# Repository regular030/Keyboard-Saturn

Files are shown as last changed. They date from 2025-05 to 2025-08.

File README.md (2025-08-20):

# **Keyboard Saturn, A Simple Keyboard With An OLED Display**

98a7035d-8480-496f-965c-6c204143d6b0



# **YouTube Video:**
https://youtu.be/Gn7tNZ5N1NY

# **Why Did I Make This**

After Hackpad, I started getting recommended lots of Scotto Keebs videos on YouTube, which made me much more interested in making my own keyboard. Now that I have more free time, I decided to make my 5-month-in-thought project a reality.

# **Design Choices**
- SN74HC165N
  - Instead of using any other GPIO expanders, I wanted to use the SN because it is an 8-bit parallel-load shift register, instead of using the I2C protocol to communicate with the MCU, which is around 8 times faster
- Raspberry Pi Pico
  - Cheap and Reliable
- OLED 32-128
  -  Just wanted to add a display where I can show whether or not NUM/CAPS/SCRL lock is on, + show Spotify music, + other stuff
- 100% Layout
  - I use the Numpad for anything numbers-related
- Minimalist chassis design
  - I just wanted to make something  that was simple and looked clean, kind of like Cybertruck, but better 
 
# **Files**
<br>
chassis
<br>

- .Step files for the chassis + PCB
  - KeyboardL.step
      - Bottom left side of keyboard
  - KeyboardM.step
      - Bottom middle side of keyboard
  - KeyboardR.step
      - Bottom right side of keyboard
  - KeyboardTop.step
      - Top side of the keyboard
      - Use M2 screws to screw it into the bottom parts (screw holes in top and bottom in the middle, left and right sections) 
  - insert-keyboard v1.step
      - The inserts for the keyboard to connect KeyboardM, KeyboardL and KeyboardR, please use super glue to make sure they are in, then super glue the chassis together
<br>
kicad
<br>

- All the KiCad 8.0.5 files for the project 

# **BOM:**


https://docs.google.com/spreadsheets/d/1oLEcZ3zztSK3hqa6-qvamrNF2S6u_cLABAHxks2xx3M/edit?usp=sharing

# THIS PROJECT IS NOW DEPRECATED. IT WILL NOT BE GETTING ANY MORE SUPPORT. V2 is a possibility

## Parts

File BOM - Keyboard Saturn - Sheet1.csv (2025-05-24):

Part Name | QTY | Price Per | Link | Notes
Raspberry Pi Pico (U1) | 1 | US $2.08
SN74HC165N (U2) | 1 | US $1.73 |  | buying one more Incase I screw up
OLED 128x32 (J1) | 1 | US $0.99
Resistor 2kohms (R1-R4) pack of 100 | 1 | US $1.67 |  | lowest # I can get
Diode IN4148 (D1-D104) pack of 100 | 2 | US $1.96
SW_Push (SW1-SW104) | 110 | US $18.13
Keyboard Keycaps pack of 126 | 1 | US $7.55
Solder Wire Desoldering | 1 | US $2.36
PCB from JLCPCB | 5 | US $31.00 |  | with tax + shipping
3D printed Case for JLCPCB | 1 | US $14.78 |  | Top only
M Screws pack of 250 | 1 | US $2.66 |  | Cheapest I could find
Total: | US $41.27 (Aliexpess) + $45.78 (PCB + top case) = USD $87.05 = $90 (prices flucates on aliexpress)

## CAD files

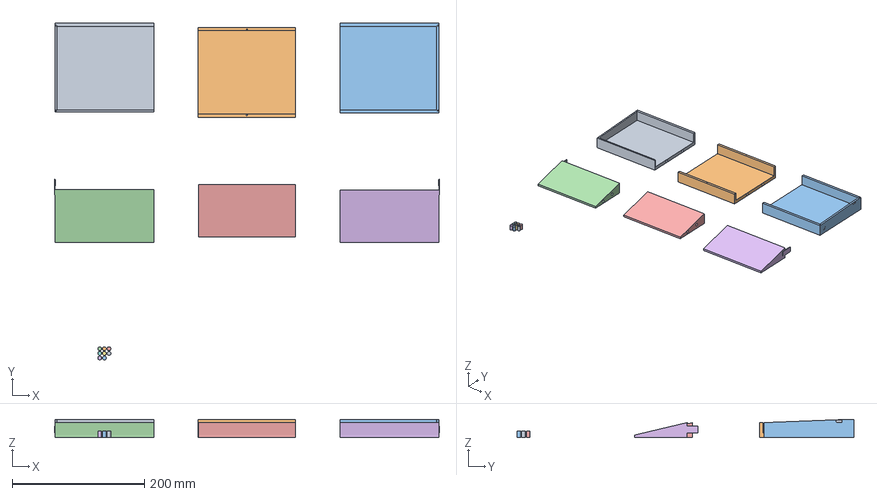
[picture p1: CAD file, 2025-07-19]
chassis/Keyboard-sliced.3mf
583.0 x 510.3 x 28.0 mm
KeyboardBot-L.stl
KeyboardBot-M.stl
KeyboardBot-R.stl
PalmRest-L.stl
PalmRest-M.stl
PalmRest-R.stl
insert-keyboard.stl x 8

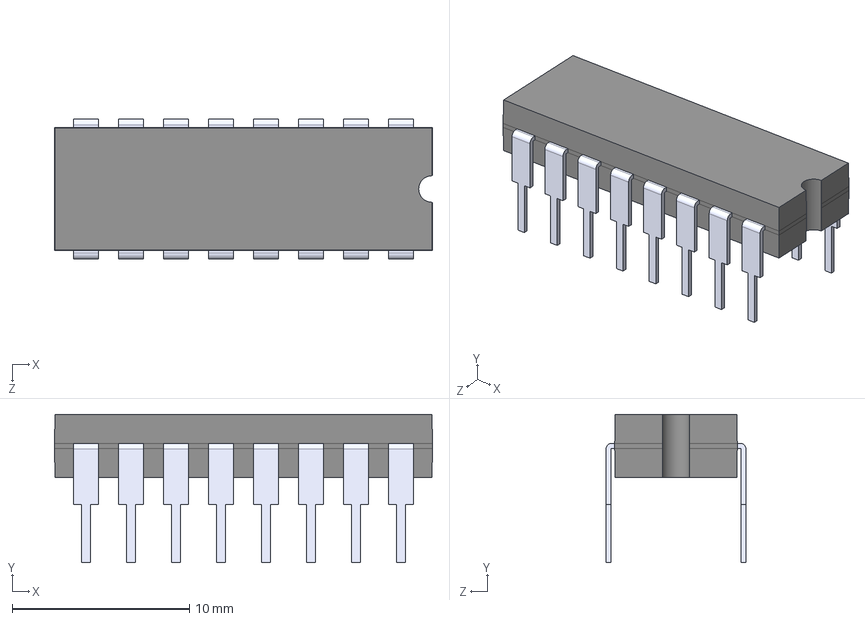
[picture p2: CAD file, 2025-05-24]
kicad/Files Needed/3dmodels/SN74HC165N.step
21.3 x 8.38 x 7.90 mm

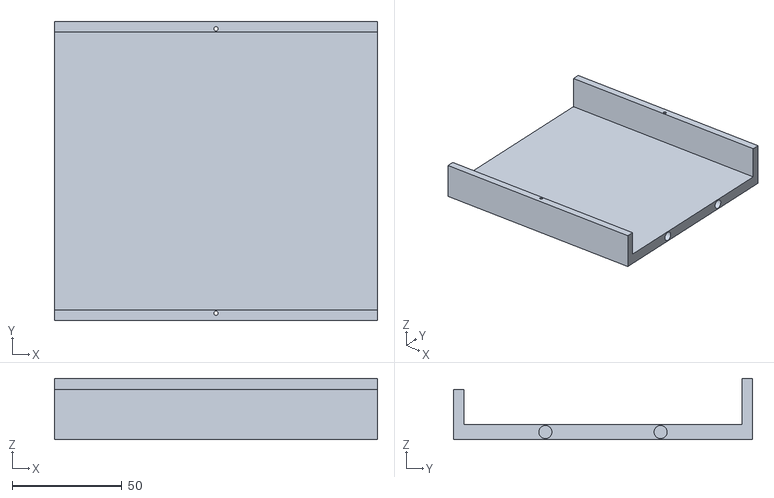
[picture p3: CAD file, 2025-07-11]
chassis/KeyboardBot-M.stl
147.3 x 136.5 x 28.0

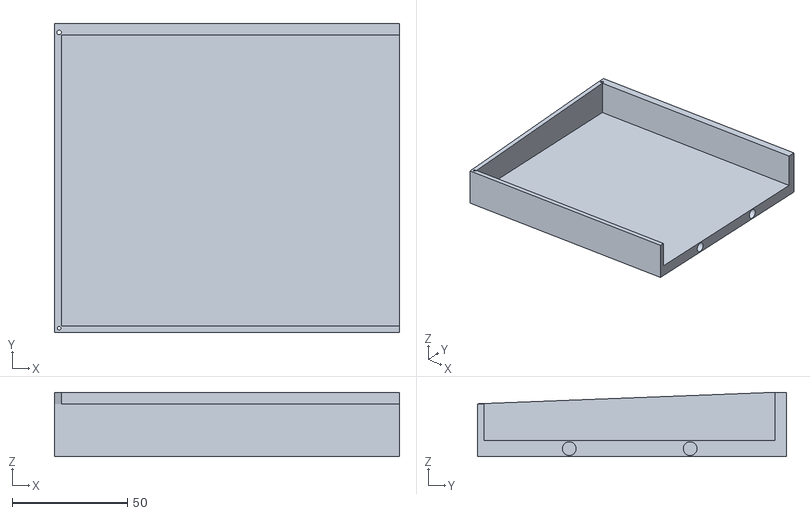
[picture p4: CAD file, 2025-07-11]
chassis/KeyboardBot-L.stl
150.0 x 134.6 x 28.0

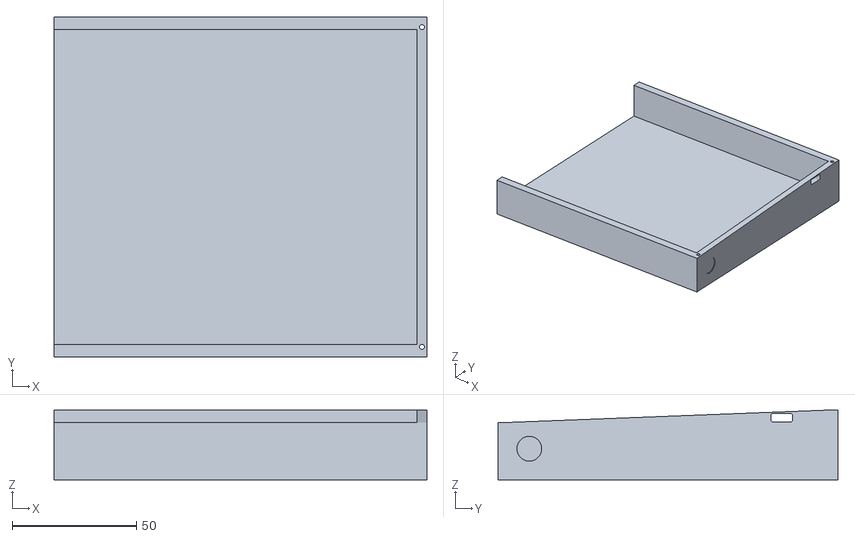
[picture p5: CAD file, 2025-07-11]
chassis/KeyboardBot-R.stl
150.0 x 136.5 x 28.0

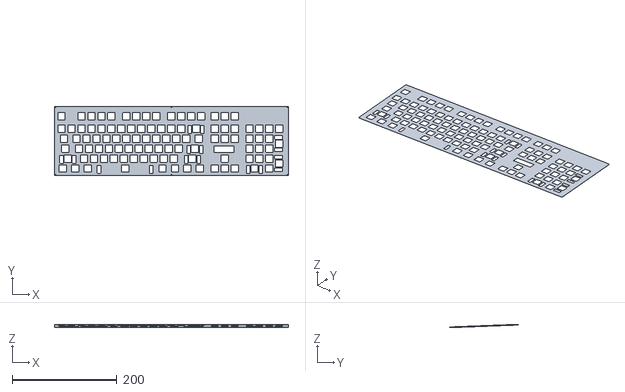
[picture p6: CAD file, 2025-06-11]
chassis/KeyboardTop.stl
447.3 x 132.5 x 6.63

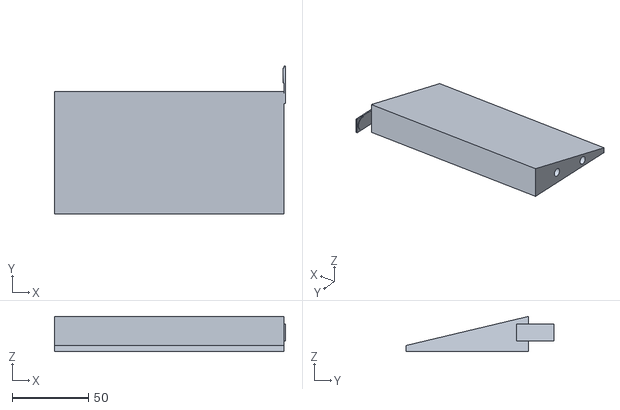
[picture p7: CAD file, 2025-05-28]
chassis/PalmRest-R.stl
151.0 x 96.6 x 23.0

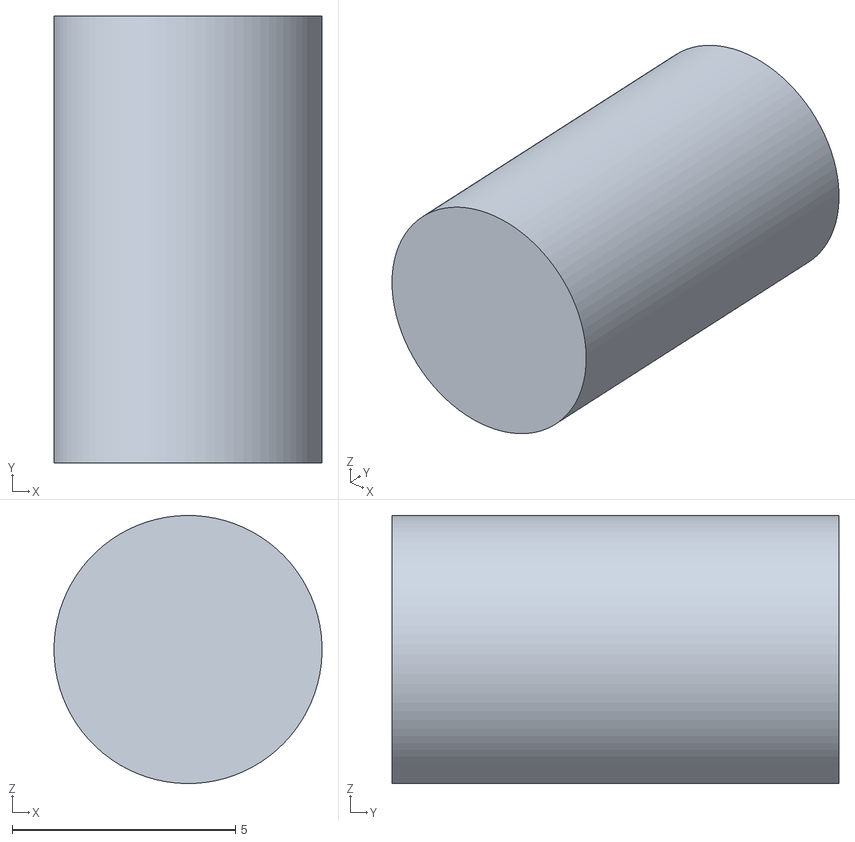
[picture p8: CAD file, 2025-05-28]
chassis/insert-keyboard.stl
6.00 x 10.0 x 6.00

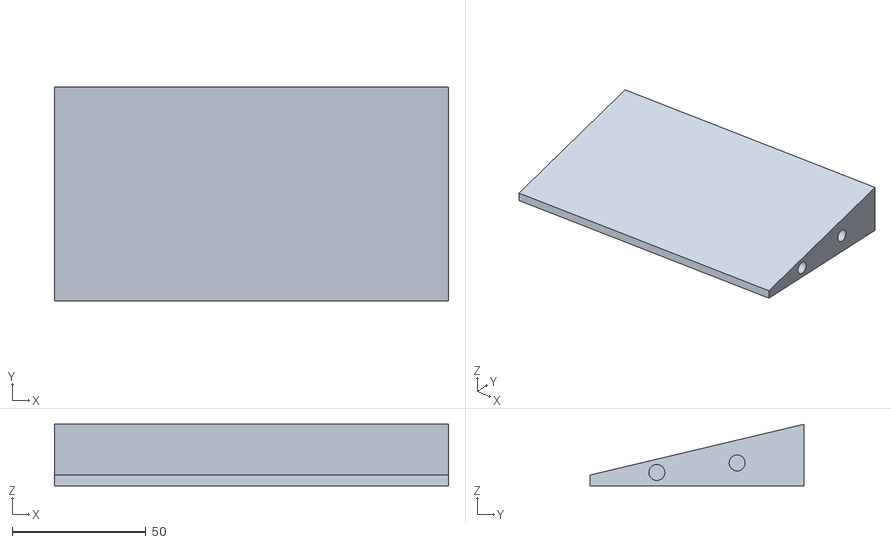
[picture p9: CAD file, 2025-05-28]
chassis/PalmRest-M.stl
147.3 x 80.0 x 23.0

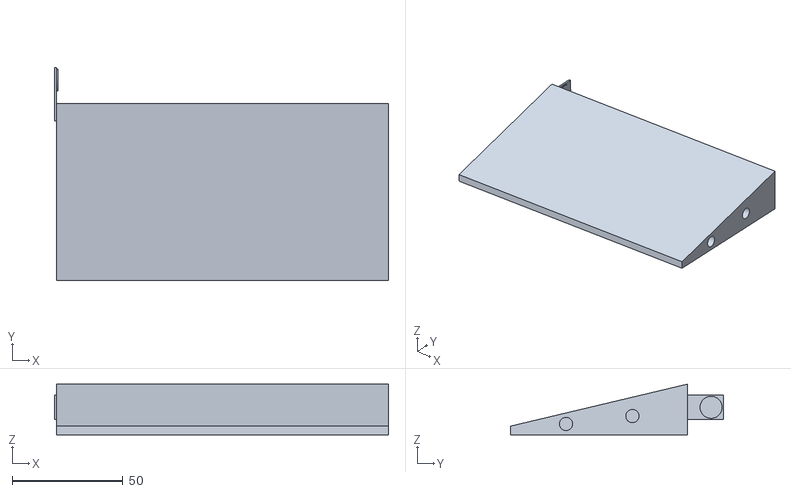
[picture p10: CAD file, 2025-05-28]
chassis/PalmRest-L.stl
151.0 x 96.1 x 23.0

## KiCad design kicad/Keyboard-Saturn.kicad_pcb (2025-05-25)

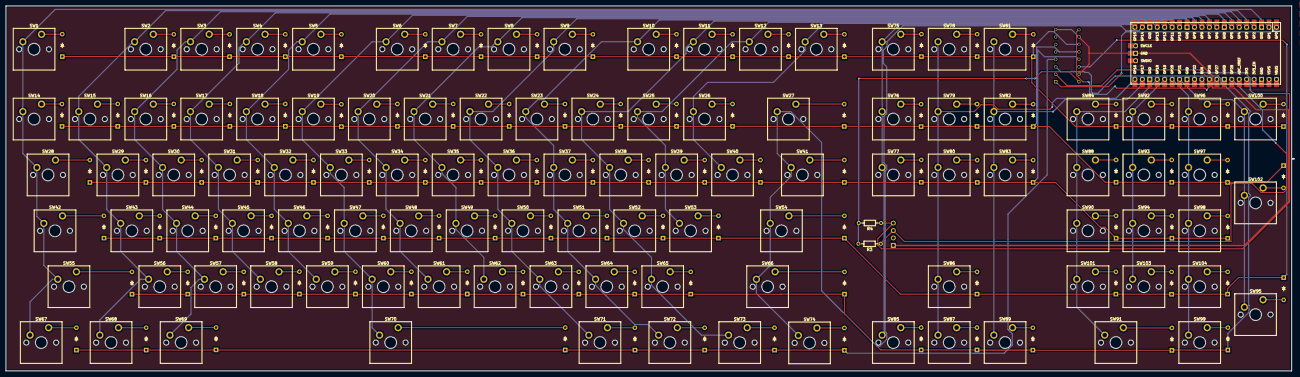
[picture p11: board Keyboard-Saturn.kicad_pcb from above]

Board: 2 copper layers, 438.9 x 124.3 mm, 213 parts (1 on the bottom side), 138 nets.

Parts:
D1, D2, D3, D4, D5, D6, D7, D8, D9, D10, D11, D12, D13, D14, D15, D16, D17, D18, D19, D20, D21, D22, D23, D24, D25, D26, D27, D28, D29, D30, D31, D32, D33, D34, D35, D36, D37, D38, D39, D40, D41, D42, D43, D44, D45, D46, D47, D48, D49, D50, D51, D52, D53, D54, D55, D56, D57, D58, D59, D60, D61, D62, D63, D64, D65, D66, D67, D68, D69, D70, D71, D72, D73, D74, D75, D76, D77, D78, D79, D80, D81, D82, D83, D84, D85, D86, D87, D88, D89, D90, D91, D92, D93, D94, D95, D96, D97, D98, D99, D100, D101, D102, D103, D104: D; Diode_DO-35
J1: OLED_128x32
R3, R4: 2k; R_Axial_DIN0204_L3.6mm_D1.6mm_P7.62mm_Horizontal
SW1, SW2, SW3, SW4, SW5, SW6, SW7, SW8, SW9, SW10, SW11, SW12, SW13, SW14, SW15, SW16, SW17, SW18, SW19, SW20, SW21, SW22, SW23, SW24, SW25, SW26, SW29, SW30, SW31, SW32, SW33, SW34, SW35, SW36, SW37, SW38, SW39, SW40, SW43, SW44, SW45, SW46, SW47, SW48, SW49, SW50, SW51, SW52, SW53, SW56, SW57, SW58, SW59, SW60, SW61, SW62, SW63, SW64, SW65, SW75, SW76, SW77, SW78, SW79, SW80, SW81, SW82, SW83, SW84, SW85, SW86, SW87, SW88, SW89, SW90, SW92, SW93, SW94, SW96, SW97, SW98, SW99, SW100, SW101, SW103, SW104: SW_Push; MX_PCB_1.00u
SW27, SW91: SW_Push; MX_PCB_2.00u
SW28, SW41: SW_Push; MX_PCB_1.50u
SW42: SW_Push; MX_PCB_1.75u
SW54, SW55: SW_Push; MX_PCB_2.25u
SW66: SW_Push; MX_PCB_2.75u
SW67, SW68, SW69, SW71, SW72, SW73, SW74: SW_Push; MX_PCB_1.25u
SW70: SW_Push; MX_PCB_6.25u
SW95, SW102: SW_Push; MX_PCB_2.00u_90deg
U1: Raspberry_Pi_Pico
U3: SN74HC165N; DIP794W45P254L1969H508Q16

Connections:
+3.3V: R3.2, R4.2, U3.16 (VCC)
GND: J1.1 (GND), U1.42 (GND), U3.8 (GND), U3.10 (SER), U3.15 (CLK_INH)
unnamed: D1.2 (A), SW1.2
unnamed: D2.2 (A), SW2.2
unnamed: D3.2 (A), SW3.2
unnamed: D4.2 (A), SW4.2
unnamed: D5.2 (A), SW5.2
unnamed: D6.2 (A), SW6.2
unnamed: D7.2 (A), SW7.2
unnamed: D8.2 (A), SW8.2
unnamed: D9.2 (A), SW9.2
unnamed: D10.2 (A), SW10.2
unnamed: D11.2 (A), SW11.2
unnamed: D12.2 (A), SW12.2
unnamed: D13.2 (A), SW13.2
unnamed: D14.2 (A), SW14.2
unnamed: D15.2 (A), SW15.2
unnamed: D16.2 (A), SW16.2
unnamed: D17.2 (A), SW17.2
unnamed: D18.2 (A), SW18.2
unnamed: D19.2 (A), SW19.2
unnamed: D20.2 (A), SW20.2
unnamed: D21.2 (A), SW21.2
unnamed: D22.2 (A), SW22.2
unnamed: D23.2 (A), SW23.2
unnamed: D24.2 (A), SW24.2
unnamed: D25.2 (A), SW25.2
unnamed: D26.2 (A), SW26.2
unnamed: D27.2 (A), SW27.2
unnamed: D28.2 (A), SW28.2
unnamed: D29.2 (A), SW29.2
unnamed: D30.2 (A), SW30.2
unnamed: D31.2 (A), SW31.2
unnamed: D32.2 (A), SW32.2
unnamed: D33.2 (A), SW33.2
unnamed: D34.2 (A), SW34.2
unnamed: D35.2 (A), SW35.2
unnamed: D36.2 (A), SW36.2
unnamed: D37.2 (A), SW37.2
unnamed: D38.2 (A), SW38.2
unnamed: D39.2 (A), SW39.2
unnamed: D40.2 (A), SW40.2
unnamed: D41.2 (A), SW41.2
unnamed: D42.2 (A), SW42.2
unnamed: D43.2 (A), SW43.2
unnamed: D44.2 (A), SW44.2
unnamed: D45.2 (A), SW45.2
unnamed: D46.2 (A), SW46.2
unnamed: D47.2 (A), SW47.2
unnamed: D48.2 (A), SW48.2
unnamed: D49.2 (A), SW49.2
unnamed: D50.2 (A), SW50.2
unnamed: D51.2 (A), SW51.2
unnamed: D52.2 (A), SW52.2
unnamed: D53.2 (A), SW53.2
unnamed: D54.2 (A), SW54.2
unnamed: D55.2 (A), SW55.2
unnamed: D56.2 (A), SW56.2
unnamed: D57.2 (A), SW57.2
unnamed: D58.2 (A), SW58.2
unnamed: D59.2 (A), SW59.2
unnamed: D60.2 (A), SW60.2
unnamed: D61.2 (A), SW61.2
unnamed: D62.2 (A), SW62.2
unnamed: D63.2 (A), SW63.2
unnamed: D64.2 (A), SW64.2
unnamed: D65.2 (A), SW65.2
unnamed: D66.2 (A), SW66.2
unnamed: D67.2 (A), SW67.2
unnamed: D68.2 (A), SW68.2
unnamed: D69.2 (A), SW69.2
unnamed: D70.2 (A), SW70.2
unnamed: D71.2 (A), SW71.2
unnamed: D72.2 (A), SW72.2
unnamed: D73.2 (A), SW73.2
unnamed: D74.2 (A), SW74.2
unnamed: D75.2 (A), SW75.2
unnamed: D76.2 (A), SW76.2
unnamed: D77.2 (A), SW77.2
unnamed: D78.2 (A), SW78.2
unnamed: D79.2 (A), SW79.2
unnamed: D80.2 (A), SW80.2
unnamed: D81.2 (A), SW81.2
unnamed: D82.2 (A), SW82.2
unnamed: D83.2 (A), SW83.2
unnamed: D84.2 (A), SW84.2
unnamed: D85.2 (A), SW85.2
unnamed: D86.2 (A), SW86.2
unnamed: D87.2 (A), SW87.2
unnamed: D88.2 (A), SW88.2
unnamed: D89.2 (A), SW89.2
unnamed: D90.2 (A), SW90.2
unnamed: D91.2 (A), SW91.2
unnamed: D92.2 (A), SW92.2
unnamed: D93.2 (A), SW93.2
unnamed: D94.2 (A), SW94.2
unnamed: D95.2 (A), SW95.2
unnamed: D96.2 (A), SW96.2
unnamed: D97.2 (A), SW97.2
unnamed: D98.2 (A), SW98.2
unnamed: D99.2 (A), SW99.2
unnamed: D100.2 (A), SW100.2
unnamed: D101.2 (A), SW101.2
unnamed: D102.2 (A), SW102.2
unnamed: D103.2 (A), SW103.2
unnamed: D104.2 (A), SW104.2
unnamed: U1.1 (GPIO0), U3.1 (SH/~LD)
unnamed: U1.31 (GPIO26_ADC0), U3.2 (CLK)
unnamed: U1.32 (GPIO27_ADC1), U3.9 (QH)
SCL: J1.3 (SCL), R3.1, U1.34 (GPIO28_ADC2)
SDA: J1.4 (SDA), R4.1, U1.29 (GPIO22)
col 1: SW1.1, SW14.1, SW28.1, SW42.1, SW55.1, SW67.1, U1.2 (GPIO1)
col 2: SW2.1, SW15.1, SW29.1, SW43.1, SW56.1, SW68.1, U1.4 (GPIO2)
col 3: SW3.1, SW16.1, SW30.1, SW44.1, SW57.1, SW69.1, U1.5 (GPIO3)
col 4: SW4.1, SW17.1, SW31.1, SW45.1, SW58.1, U1.6 (GPIO4)
col 5: SW5.1, SW18.1, SW32.1, SW46.1, SW59.1, U1.7 (GPIO5)
col 6: SW6.1, SW19.1, SW33.1, SW47.1, SW60.1, SW70.1, U1.9 (GPIO6)
col 7: SW7.1, SW20.1, SW34.1, SW48.1, SW61.1, U1.10 (GPIO7)
col 8: SW8.1, SW21.1, SW35.1, SW49.1, SW62.1, U1.11 (GPIO8)
col 9: SW9.1, SW22.1, SW36.1, SW50.1, SW63.1, SW71.1, U1.12 (GPIO9)
col 10: SW10.1, SW23.1, SW37.1, SW51.1, SW64.1, SW72.1, U1.14 (GPIO10)
col 11: SW11.1, SW24.1, SW38.1, SW52.1, SW65.1, SW73.1, U1.15 (GPIO11)
col 12: SW12.1, SW25.1, SW39.1, SW53.1, U1.16 (GPIO12)
col 13: SW13.1, SW26.1, SW40.1, U1.17 (GPIO13)
col 14: SW27.1, SW41.1, SW54.1, SW66.1, SW74.1, U1.19 (GPIO14)
col 15: SW75.1, SW76.1, SW77.1, SW85.1, U1.20 (GPIO15)
col 16: SW78.1, SW79.1, SW80.1, SW86.1, SW87.1, U1.21 (GPIO16)
col 17: SW81.1, SW82.1, SW83.1, SW89.1, U1.22 (GPIO17)
col 18: SW84.1, SW88.1, SW90.1, SW91.1, SW101.1, U1.24 (GPIO18)
col 19: SW92.1, SW93.1, SW94.1, SW103.1, U1.25 (GPIO19)
col 20: SW96.1, SW97.1, SW98.1, SW99.1, SW104.1, U1.26 (GPIO20)
col 21: SW95.1, SW100.1, SW102.1, U1.27 (GPIO21)
row 1: D1.1 (K), D2.1 (K), D3.1 (K), D4.1 (K), D5.1 (K), D6.1 (K), D7.1 (K), D8.1 (K), D9.1 (K), D10.1 (K), D11.1 (K), D12.1 (K), D13.1 (K), D75.1 (K), D78.1 (K), D81.1 (K), D84.1 (K), D92.1 (K), D96.1 (K), D100.1 (K), U3.11 (A)
row 2: D14.1 (K), D15.1 (K), D16.1 (K), D17.1 (K), D18.1 (K), D19.1 (K), D20.1 (K), D21.1 (K), D22.1 (K), D23.1 (K), D24.1 (K), D25.1 (K), D26.1 (K), D27.1 (K), D76.1 (K), D79.1 (K), D82.1 (K), D88.1 (K), D93.1 (K), D97.1 (K), D102.1 (K), U3.12 (B)
row 3: D28.1 (K), D29.1 (K), D30.1 (K), D31.1 (K), D32.1 (K), D33.1 (K), D34.1 (K), D35.1 (K), D36.1 (K), D37.1 (K), D38.1 (K), D39.1 (K), D40.1 (K), D41.1 (K), D77.1 (K), D80.1 (K), D83.1 (K), D90.1 (K), D94.1 (K), D98.1 (K), U3.13 (C)
row 4: D42.1 (K), D43.1 (K), D44.1 (K), D45.1 (K), D46.1 (K), D47.1 (K), D48.1 (K), D49.1 (K), D50.1 (K), D51.1 (K), D52.1 (K), D53.1 (K), D54.1 (K), D86.1 (K), D95.1 (K), D101.1 (K), D103.1 (K), D104.1 (K), U3.14 (D)
row 5: D55.1 (K), D56.1 (K), D57.1 (K), D58.1 (K), D59.1 (K), D60.1 (K), D61.1 (K), D62.1 (K), D63.1 (K), D64.1 (K), D65.1 (K), D66.1 (K), D85.1 (K), D87.1 (K), D89.1 (K), D91.1 (K), D99.1 (K), U3.3 (E)
row 6: D67.1 (K), D68.1 (K), D69.1 (K), D70.1 (K), D71.1 (K), D72.1 (K), D73.1 (K), D74.1 (K), U3.4 (F)

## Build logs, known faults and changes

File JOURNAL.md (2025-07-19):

---
title: "Keyboard Saturn"
author: "Kunshpreet"
description: "Simple Keyboard with OLED screen"
---

**Total time spent thus far: 70h**

# January: Research 

- Started looking at how to make my keyboard (looking at YouTube videos, etc) 
- Created a plan
  - Make the keyboard a 100% layout
  - Add an OLED screen to display extra info 
- Started thinking about what components to use (what type of switches,e.g., red, brown, blue, etc.)
- Started looking at the pinout of the Pi Pico (my microcontroller)

**Total time spent: 5h**

# May 17-20: PCB making 

- started creating the PCB
- Found out that the PI Pico doesn't have enough pins for my matrix for the keys
  - Thought about using Japanese matrices, but instead I opted to use the MCP23017_SO since I want to learn how to solder SMD components 
- After creating the schematic, I posted it on Slack to get some feedback

- Then I started creating the PCB itself
- Routing was hard, so for the first time, I used Vias

**Total time spent: 15h**

# May 20-22: Making the chassis 

- started creating the chassis
- Since I'm using somewhat custom spacing, it took a long time to make the top part of my keyboard


- Once done, I started making the bottom part
- After that, I started seeing how I was going to print out the chassis
  - JLC charges 100$ for the chassis
- So instead, I made the chassis printable by splitting it into 3 parts and joining them via these standoffs that I made

**Total time spent: 8h**

# May 22-23: Creating BOM

- BOM done, please check the read me
**Total time spent: 4h**

# May 23: Updating Readme and other things

- Readme updated
**Total time spent: 2h**

# May 23 - 24: Firmware 

- Started making firmware
  - took too long setting up QMK (like 5 hours in one day) 
- Found out the MCP23017_SO is way too slow since it's using the I2C connection protocol
  - Instead im using the SN74HC165N, which uses the spi protocal which is 100x faster
  - replaced it in the PCB
- made the keyboard layout for my keyboard in QMK
May 24th:
- Took almost 5 hours to make the keyboard work, not even including the custom matrix
    - Not good with command-based apps, so I need to work on this in the future
- made a custom matrix to read from the SN74HC165N
    - TOOK A LONG TIME JUST TO LEARN HOW TO DO IT
- made the OLED work
- Here are some code issues that I had today:
  - setPinOutput(MATRIX_COL_PINS[c]) failed because the macro received 21 arguments instead of 1, likely because MATRIX_COL_PINS[c] expands improperly.
  - writePinHigh(MATRIX_COL_PINS[c]) and writePinLow(MATRIX_COL_PINS[col]) also failed due to the same macro argument issue.
  - Macros like gpio_set_pin_output_push_pull, gpio_write_pin_high, and gpio_write_pin_low were not recognized as functions; they're macros and not meant to handle complex input.
  - matrix_scan_change is used without declaration, leading to an implicit function declaration error.
  - All warnings were treated as errors (-Werror flag), causing the build to fail on these issues.
**Total time spent: 15h**

# May 28: Created Palm Rest:
- Created a palm rest on the keyboard
- Added the 3mf file for the print
  

**Total time spent: 2h**

# July 1–18: OLED Debugging & Firmware Migration (QMK → Arduino)

**Total time spent: ~20h**



Matrix Ghosting & Pull-Down Resistor Fix

- Began debugging ghosting issues in the keyboard matrix — noticed that random key presses were being registered without input.
- Discovered I had forgotten to add 10k pull-down resistors to the inputs of the SN74HC165N shift registers.
- This caused the lines to float, resulting in unpredictable input states.
- Therefore, I had to add a delay in code, resulting in a ~700ms delay (around 70x slower than a normal keyboard)

SoftI2C and RP2040 Pin Constraints

- Realized that the OLED was connected to non-native I2C pins (e.g., GPIO 22, 28) on the RP2040.
- Switched to using SoftI2C to bit-bang I2C over any pins.
- With SoftI2C, successfully scanned and detected the OLED at address 0x3C.

OLED Font Rendering

- Created a simple text rendering function to write characters pixel-by-pixel on the OLED.
- Initially, embedded all font bitmaps directly in the .ino file.
- Later refactored by moving font data into a dedicated .h file for clarity and reuse.

Migrating from QMK to Arduino IDE

- QMK was becoming too complex to support:
  - SPI reads from SN74HC165N
  - SoftI2C for OLED
  - Custom wiring constraints
- Fully **migrated to Arduino IDE**, which provided:
  - Lower-level hardware access
  - Simplified debugging with Serial.print()
  - Better development velocity for custom hardware

Hardware Rework: 3.3V Connection Fix

- Final keyboard assembly showed no power to the RP2040 MCU.
- Diagnosed the issue and found that the 3.3V line wasn’t connected to the MCU.
- Board was already fully soldered — had to use jumper wires to connect 3.3V to the correct pin on the MCU manually.
- After rework, the SN74HC165N and OLED powered up correctly.

# THIS PROJECT IS NOW DEPRECATED. IT WILL NOT BE GETTING ANY MORE SUPPORT. V2 is a possibility

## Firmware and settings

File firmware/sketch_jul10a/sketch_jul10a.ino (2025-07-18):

#include <SoftI2C.h>
#include <Arduino.h>
#include <Keyboard.h>
#include "font5x7.h"  // Your separate font header with font5x7 array

#define SDA_PIN 22
#define SCL_PIN 28

SoftI2C SoftWire(SDA_PIN, SCL_PIN);

#define OLED_ADDR 0x3C

// OLED command and data functions (same as before)
void oled_command(uint8_t cmd) {
  SoftWire.beginTransmission(OLED_ADDR);
  SoftWire.write(0x00); // command mode
  SoftWire.write(cmd);
  SoftWire.endTransmission();
}

void oled_data(uint8_t *data, size_t len) {
  SoftWire.beginTransmission(OLED_ADDR);
  SoftWire.write(0x40); // data mode
  for (size_t i=0; i<len; i++) SoftWire.write(data[i]);
  SoftWire.endTransmission();
}

void oled_init() {
  oled_command(0xAE); oled_command(0xD5); oled_command(0x80);
  oled_command(0xA8); oled_command(0x1F);
  oled_command(0xD3); oled_command(0x00);
  oled_command(0x40);
  oled_command(0x8D); oled_command(0x14);
  oled_command(0x20); oled_command(0x00);
  oled_command(0xA1); oled_command(0xC8);
  oled_command(0xDA); oled_command(0x02);
  oled_command(0x81); oled_command(0x8F);
  oled_command(0xD9); oled_command(0xF1);
  oled_command(0xDB); oled_command(0x40);
  oled_command(0xA4); oled_command(0xA6);
  oled_command(0xAF);
}

void oled_clear() {
  uint8_t zero[128] = {0};
  for (uint8_t page=0; page<4; page++) {
    oled_command(0xB0 + page);
    oled_command(0x00);
    oled_command(0x10);
    oled_data(zero, 128);
  }
}

// Draw one character at (page, col)
void oled_draw_char(char c, uint8_t page, uint8_t col) {
  if (c < 32 || c > 126) c = '?';
  const uint8_t* bitmap = font5x7[c - 32];
  oled_command(0xB0 + page);
  oled_command(0x00 + (col & 0x0F));
  oled_command(0x10 + ((col >> 4) & 0x0F));
  uint8_t buf[6];
  memcpy(buf, bitmap, 5);
  buf[5] = 0x00;
  oled_data(buf, 6);
}

// Draw string starting at page and column
void oled_draw_string(const char* str, uint8_t page, uint8_t col) {
  while (*str && col < 128 - 6) {
    oled_draw_char(*str++, page, col);
    col += 6;
  }
}

// Keyboard matrix definitions
#define DEBUG_MODE false

const uint8_t ROWS = 6;
const uint8_t COLS = 21;

const uint8_t colPins[COLS] = {
   1,  2,  3,  4,  5,  6,  7,
   8,  9, 10, 11, 12, 13, 14,
  15, 16, 17, 18, 19, 20, 21
};

#define SN_LOAD_PIN  0
#define SN_CLK_PIN   26
#define SN_DATA_PIN  27

const char* keymap[ROWS][COLS] = {
  {"ESC", "F1", "F2", "F3", "F4", "F5", "F6", "F7", "F8", "F9", "F10", "F11", "F12", "____", "PSCR", "SLCK", "PAUS", "NUM", "NP_/", "NP_*", "NP_-"},
  {"`", "1", "2", "3", "4", "5", "6", "7", "8", "9", "0", "-", "=", "BSPC", "INS", "HOME", "PGUP", "NP_7", "NP_8", "NP_9", "NP_+"},
  {"TAB", "Q", "W", "E", "R", "T", "Y", "U", "I", "O", "P", "[", "]", "\\", "DEL", "END", "PGDN", "NP_4", "NP_5", "NP_6", "____"},
  {"CAPS", "A", "S", "D", "F", "G", "H", "J", "K", "L", ";", "'", "____", "ENTER", "____", "UP", "____", "NP_1", "NP_2", "NP_3", "NP_ENTER"},
  {"LSHFT", "Z", "X", "C", "V", "B", "N", "M", ",", ".", "/", "____", "____", "RSHFT", "____", "LEFT", "DOWN", "RIGHT", "NP_0", "____", "NP_."},
  {"LCTRL", "LGUI", "LALT", "____", "____", "SPACE", "____", "____", "RALT", "MENU", "RGUI", "____", "____", "RCTRL", "____", "____", "____", "____", "____", "____"}
};

char getShiftedSymbol(char key) {
  switch (key) {
    case '1': return '!';
    case '2': return '@';
    case '3': return '#';
    case '4': return '$';
    case '5': return '%';
    case '6': return '^';
    case '7': return '&';
    case '8': return '*';
    case '9': return '(';
    case '0': return ')';
    case '-': return '_';
    case '=': return '+';
    case '[': return '{';
    case ']': return '}';
    case '\\': return '|';
    case ';': return ':';
    case '\'': return '"';
    case ',': return '<';
    case '.': return '>';
    case '/': return '?';
    case '`': return '~';
    default: return 0;
  }
}

bool capsLockActive = false;
bool shiftActive = false;

uint8_t getKeyCode(const char* label, bool& useShift) {
  useShift = false;

  if (strcmp(label, "ENTER") == 0) return KEY_RETURN;
  if (strcmp(label, "ESC") == 0) return KEY_ESC;
  if (strcmp(label, "BSPC") == 0) return KEY_BACKSPACE;
  if (strcmp(label, "TAB") == 0) return KEY_TAB;
  if (strcmp(label, "SPACE") == 0) return ' ';
  if (strcmp(label, "DEL") == 0) return KEY_DELETE;
  if (strcmp(label, "UP") == 0) return KEY_UP_ARROW;
  if (strcmp(label, "DOWN") == 0) return KEY_DOWN_ARROW;
  if (strcmp(label, "LEFT") == 0) return KEY_LEFT_ARROW;
  if (strcmp(label, "RIGHT") == 0) return KEY_RIGHT_ARROW;

  if (strlen(label) == 1) {
    char ch = label[0];

    if (ch >= 'a' && ch <= 'z') {
      if ((capsLockActive && !shiftActive) || (!capsLockActive && shiftActive)) {
        useShift = true;
      }
      return tolower(ch);
    }

    char shifted = getShiftedSymbol(ch);
    if (shifted != 0 && shiftActive) {
      useShift = true;
      return shifted;
    }

    return ch;
  }

  return 0;
}

uint8_t readRows() {
  digitalWrite(SN_LOAD_PIN, LOW);
  delayMicroseconds(3);
  digitalWrite(SN_LOAD_PIN, HIGH);
  delayMicroseconds(3);

  uint8_t data = 0;
  for (int i = 0; i < 8; i++) {
    data <<= 1;
    digitalWrite(SN_CLK_PIN, LOW);
    delayMicroseconds(1);
    data |= digitalRead(SN_DATA_PIN);
    digitalWrite(SN_CLK_PIN, HIGH);
    delayMicroseconds(1);
  }

  return data;
}

void setup() {
  Serial.begin(115200);
  Keyboard.begin();

  SoftWire.begin();

  oled_init();
  oled_clear();
  oled_draw_string("Ready...", 1, 0);

  for (uint8_t c = 0; c < COLS; c++) {
    pinMode(colPins[c], OUTPUT);
    digitalWrite(colPins[c], LOW);
  }

  pinMode(SN_LOAD_PIN, OUTPUT);
  pinMode(SN_CLK_PIN, OUTPUT);
  pinMode(SN_DATA_PIN, INPUT);

  digitalWrite(SN_LOAD_PIN, HIGH);
  digitalWrite(SN_CLK_PIN, HIGH);

  Serial.println("Matrix scanner initialized.");
}

void loop() {
  static bool rowDetected[8] = {false};

  for (uint8_t col = 0; col < COLS; col++) {
    for (uint8_t c = 0; c < COLS; c++) digitalWrite(colPins[c], LOW);
    digitalWrite(colPins[col], HIGH);
    delay(30);

    digitalWrite(SN_LOAD_PIN, LOW);
    delayMicroseconds(5);
    digitalWrite(SN_LOAD_PIN, HIGH);
    delayMicroseconds(5);

    uint8_t rowBits = readRows();
    digitalWrite(colPins[col], LOW);

    for (uint8_t bit = 0; bit < ROWS; bit++) {
      bool isPressed = (rowBits >> bit) & 1;
      if (isPressed && !rowDetected[bit]) {
        rowDetected[bit] = true;

        const char* label = keymap[bit][col];
        if (!label || strcmp(label, "____") == 0) continue;

        if (DEBUG_MODE) {
          Serial.println(label);
        } else {
          if (strcmp(label, "CAPS") == 0) {
            capsLockActive = !capsLockActive;
            Serial.println(capsLockActive ? "CAPS ON" : "CAPS OFF");
            continue;
          }

          if (strcmp(label, "LSHFT") == 0 || strcmp(label, "RSHFT") == 0) {
            shiftActive = true;
            continue;
          }

          bool useShift = false;
          uint8_t keycode = getKeyCode(label, useShift);

          if (keycode != 0) {
            if (useShift) Keyboard.press(KEY_LEFT_SHIFT);
            Keyboard.press(keycode);
            delay(5);
            Keyboard.release(keycode);
            if (useShift) Keyboard.release(KEY_LEFT_SHIFT);
          }

          shiftActive = false;

          // Display pressed key on OLED
          oled_clear();
          oled_draw_string(label, 1, 0);
        }
      }
      else if (!isPressed) {
        // Reset detection for that row so next press can be detected
        rowDetected[bit] = false;
      }
    }
  }

  delay(10);
}

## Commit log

2025-05-20 Updated names
    [Keyboard-Saturn.kicad_pcb, Keyboard-Saturn.kicad_sch]
2025-05-20 updated some documentation
    [Keyboard-Saturn.kicad_pcb, Keyboard-Saturn.kicad_sch]
2025-05-21 chassis v1
    [Keyboard-Saturn.kicad_pcb, saturnChassis v1.step]
2025-05-21 chassis final???
    [Keyboard-Saturn.kicad_pcb, saturnChassis v1.step, saturnChassis-bottom.step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]
2025-05-23 made my chassis printable on a a1m
    [KeyboardL.step, KeyboardM.step, KeyboardR-.step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]
2025-05-23 file reorg
    [Keyboard-Saturn.kicad_pcb, Keyboard-Saturn.kicad_sch, KeyboardL.step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]
2025-05-24 added SN34HC165N to kicad
    [Keyboard-Saturn.kicad_pcb, Keyboard-Saturn.kicad_sch, SN74HC165N.step]
2025-05-24 generate gerber, update PCB step + finshed PCB wiring
    [Keyboard-Saturn-B_Cu.gbr, Keyboard-Saturn-B_Mask.gbr, Keyboard-Saturn-B_Paste.gbr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]
2025-05-24 update 3d model, and added copper fills
    [Keyboard-Saturn-B_Cu.gbr, Keyboard-Saturn-B_Mask.gbr, Keyboard-Saturn-B_Paste.gbr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]
2025-05-24 Update BOM - Keyboard Saturn - Sheet1.csv
    [BOM - Keyboard Saturn - Sheet1.csv]
2025-05-25 90% done firmware, updated kicad files to match code
    [Keyboard-Saturn-B_Cu.gbr, Keyboard-Saturn-B_Mask.gbr, Keyboard-Saturn-B_Paste.gbr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]
2025-05-28 added palm rest on keyboard
    [Keyboard-sliced.3mf, KeyboardBot-L.stl, KeyboardBot-M.stl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]
2025-05-29 realized there was a hole missing on keyboardBotL and R
    [Keyboard-sliced.3mf, KeyboardBot-L.stl, KeyboardBot-R.stl]
2025-07-11 moved code to arudino ide, keyboard works, more stuff coming soon
    [Keyboard-sliced.3mf, KeyboardBot-L.stl, KeyboardBot-M.stl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]
